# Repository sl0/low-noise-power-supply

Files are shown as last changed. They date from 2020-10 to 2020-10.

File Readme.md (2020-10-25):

# Low noise power supply

Noise on the power supply is disturbing, especially when you have some RF
components. Recently I got a hint to a work of Bernhard DG4RBF about his
paper on
[Rauschmessungen am LM723][].

Thanks to DF7KB and DC6CM for their helpful details and verifying the schema and the PCB,
which finally led to this KiCAD version using a LM723 and a PNP
transistor BD244C.

The files in the kicad directoy are licensed under the terms of the definition
for Open Source Hardware Association.

It is a simple schema as screenshot from my KiCAD session:

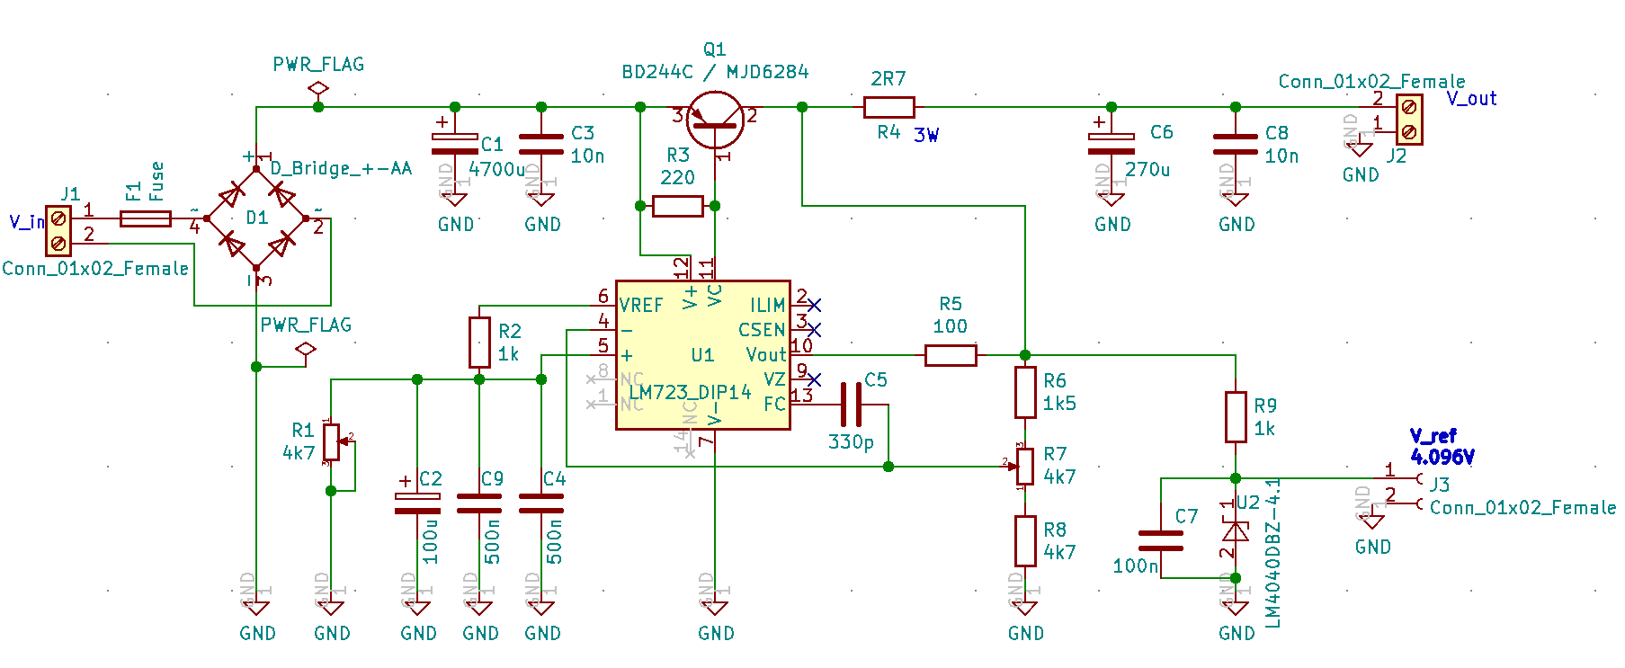
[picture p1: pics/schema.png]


You have to decide which Voltage you need:

 - Output lower than 7.15 V:

    use R1 for adjusting, R7 may be replaced by a wire on pins 3+2, R8 is not needed at all.

 - Output greater than 7.15 V:

    use R7 for adjusting, R1 is not needed

C4 is doubled now with C9, ultra low noise should use 1000nF in sum.

If you don't need the ultra low noise feature, just bridge R4 and
reduce C4, C9 to 100nF.

R9, C7 and U2 provide a reference voltage, f.e. for ardiuno Aref to
make exact measurements possible. If you you don't need this, just
omit them on the pcb.

Have fun!

[Rauschmessungen am LM723]: https://dg4rbf.lima-city.de/Rauschmessungen%20am%20LM723.pdf

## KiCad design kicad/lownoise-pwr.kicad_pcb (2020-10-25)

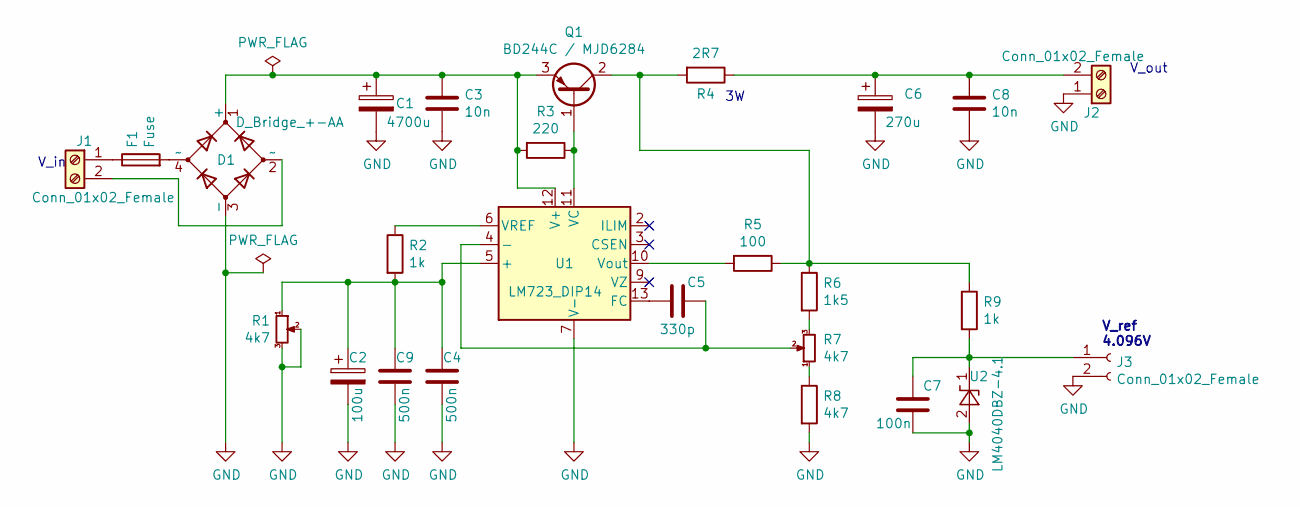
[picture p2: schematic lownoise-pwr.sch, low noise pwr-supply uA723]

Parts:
C1: 4700u; C_Radial_D18.0mm_H35.5mm_P7.50mm
C2: 100u; C_Radial_D8.0mm_H7.0mm_P3.50mm
C3, C8: 10n; C_1206_3216Metric_Pad1.42x1.75mm_HandSolder
C4, C9: 500n; C_Disc_D5.0mm_W2.5mm_P2.50mm
C5: 330p; C_Radial_D5.0mm_H7.0mm_P2.00mm
C6: 270u; C_Radial_D8.0mm_H11.5mm_P3.50mm
C7: 100n; C_1210_3225Metric_Pad1.42x2.65mm_HandSolder
D1: D_Bridge_+-AA; Diode_Bridge_15.2x15.2x6.3mm_P10.9mm
F1: Fuse; Fuseholder_Cylinder-5x20mm_Schurter_0031_8201_Horizontal_Op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
J1, J2: Conn_01x02_Female; TerminalBlock_Phoenix_MKDS-3-2-5.08_1x02_P5.08mm_Horizontal
J3: Conn_01x02_Female; PinHeader_1x02_P2.54mm_Vertical
Q1: BD244C / MJD6284; TO-247-3_Vertical
R1, R7: 4k7; Potentiometer_Bourns_3296W_Vertical
R2: 1k; R_Axial_DIN0207_L6.3mm_D2.5mm_P7.62mm_Horizontal
R3: 220; R_Axial_DIN0207_L6.3mm_D2.5mm_P7.62mm_Horizontal
R4: 2R7; R_Axial_DIN0516_L15.5mm_D5.0mm_P5.08mm_Vertical
R5: 100; R_Axial_DIN0207_L6.3mm_D2.5mm_P7.62mm_Horizontal
R6: 1k5; R_Axial_DIN0207_L6.3mm_D2.5mm_P7.62mm_Horizontal
R8: 4k7; R_Axial_DIN0207_L6.3mm_D2.5mm_P7.62mm_Horizontal
R9: 1k; R_1206_3216Metric_Pad1.42x1.75mm_HandSolder
U1: LM723_DIP14; DIP-14_W7.62mm
U2: LM4040DBZ-4.1; SOT-23

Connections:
GND: C1.2, C2.2, C3.2, C4.2, C6.2, C7.2, C8.2, C9.2, D1.3 (-), J2.1, J3.2, R1.2, R1.3, R8.2, U1.7 (V-), U2.2 (A)
unnamed: C1.1, C3.1, D1.1 (+), Q1.3 (E), R3.2, U1.12 (V+)
unnamed: C2.1, C4.1, C9.1, R1.1, R2.2, U1.5 (+)
unnamed: C5.1, R7.2, U1.4 (-)
unnamed: C5.2, U1.13 (FC)
unnamed: C6.1, C8.1, J2.2, R4.1
unnamed: C7.1, J3.1, R9.2, U2.1 (K)
unnamed: D1.2 (~~), J1.2
unnamed: D1.4 (~~), F1.2
unnamed: F1.1, J1.1
unnamed: Q1.1 (B), R3.1, U1.11 (VC)
unnamed: Q1.2 (C), R4.2, R5.1, R6.1, R9.1
unnamed: R2.1, U1.6 (VREF)
unnamed: R5.2, U1.10 (Vout)
unnamed: R6.2, R7.3
unnamed: R7.1, R8.1

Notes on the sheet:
V_ref 4.096V
V_out
V_in

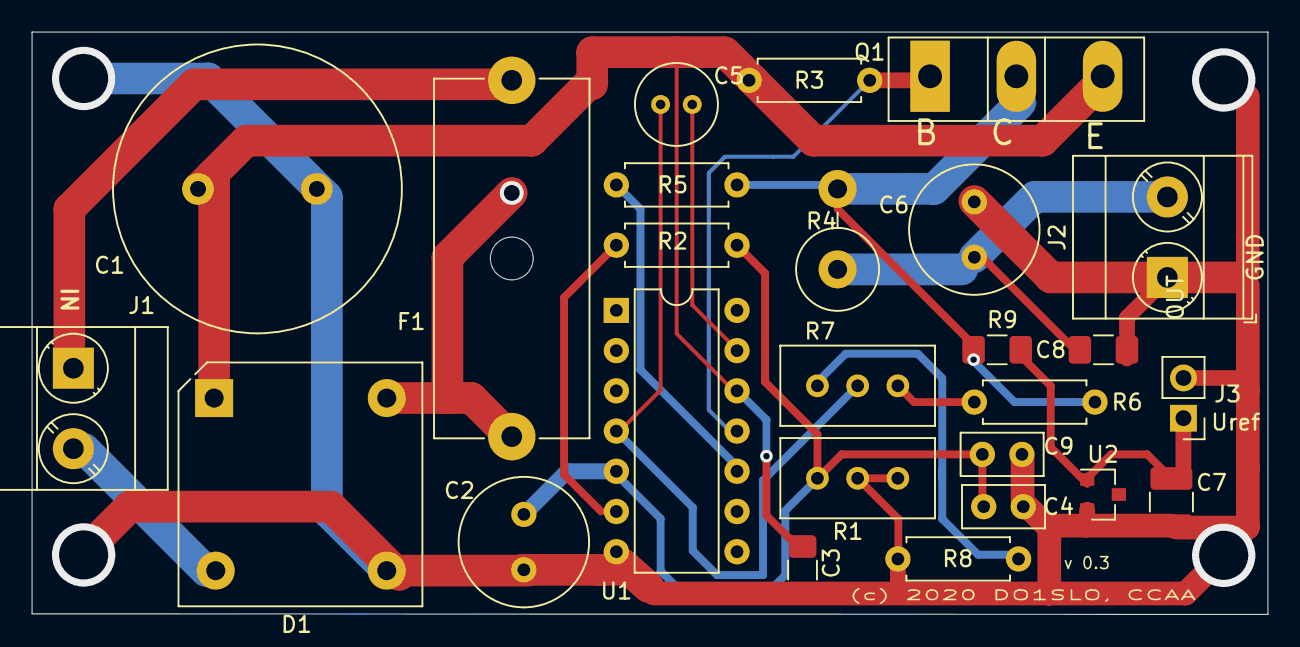
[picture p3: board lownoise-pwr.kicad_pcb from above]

Board: 2 copper layers, 78.0 x 36.8 mm, 26 parts (0 on the bottom side), 16 nets.

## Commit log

2020-03-11 Ignores kicad *bak
2020-03-11 Adds KiCAD Files
    [lownoise-pwr.kicad_pcb, lownoise-pwr.sch]
2020-03-11 Missing Kicad files no longer mentioned in Readme
2020-03-27 Enlarge power pins in and out
    [lownoise-pwr.kicad_pcb]
2020-03-29 Exports gerber files and zip for upload
    [lownoise-pwr-B_Cu.gbr, lownoise-pwr-B_Mask.gbr, lownoise-pwr-B_Paste.gbr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]
2020-07-21 Starts long way to screw-plugs
    [lownoise-pwr.kicad_pcb, lownoise-pwr.sch]
2020-07-22 Adds output screw-plugs, big transistor
    R4 now vertical to gain space for screw-plugs
    Input srew-plug not completely on PCB, soldered wires preferred
    Adds 2nd via to solder polymer-fuse instead of glas fuseholder
    [lownoise-pwr.kicad_pcb, lownoise-pwr.sch]
2020-07-23 Adds gerber production files
    Modifies kicad_pcb file as well due to gerber export settings
    Gerber settings found there:
    https://support.jlcpcb.com/article/102-kicad-515---generating-gerber-and-drill-files
    [lownoise-pwr-B_Cu.gbr, lownoise-pwr-B_Mask.gbr, lownoise-pwr-B_Paste.gbr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]
2020-10-25 Adds another C to ensure bigger capacity is possible
    Reason: components local availability
    [lownoise-pwr.sch]
2020-10-25 Ensure distance to pcb-edge, places C4, C9
    New component requires redesign
    [lownoise-pwr.kicad_pcb]

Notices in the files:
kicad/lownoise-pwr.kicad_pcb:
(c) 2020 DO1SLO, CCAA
